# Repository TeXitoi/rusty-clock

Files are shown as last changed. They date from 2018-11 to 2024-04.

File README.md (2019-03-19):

# Rusty clock 

An alarm clock in pure bare metal embedded rust (no OS). It features pressure, temperature, humidity, monophonic alarm on a e-paper display. The 5 programmable alarms can ring one time (and never repeat) or every week day that you want (for example only Monday and Thursday).

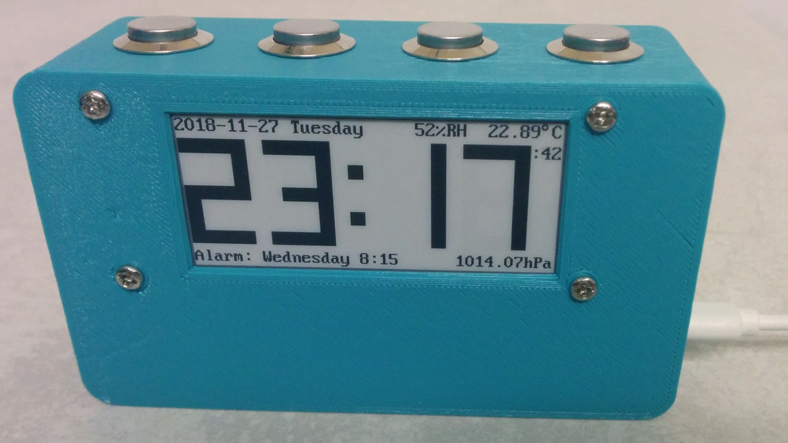
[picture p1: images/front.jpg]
front


You can also look at the [gallery](gallery.md).

## Hardware

The hardware used in this project is
- a [blue pill board](https://wiki.stm32duino.com/index.php?title=Blue_Pill) featuring a STM32F103C8 microcontroller (20KiB RAM, 64 KiB flash, ARM Cortex M3 @72MHz);
- a [2.9" WaveShare e-paper display](https://www.waveshare.com/wiki/2.9inch_e-Paper_Module) (296x128 black or white pixels);
- a [BME280 sensor](https://www.bosch-sensortec.com/bst/products/all_products/bme280) for temperature, humidity and pressure on a [I2C compatible PCB (VIN, GND, SCL and SDA pins)](https://www.aliexpress.com/item/a/32847825408.html);
- a [2" speaker](https://www.aliexpress.com/item/a/32728713916.html) driven by PWM;
- 4 [16mm normally open push buttons](https://www.aliexpress.com/item/a/32867071630.html) (cancel, previous, next, OK);
- a [3D printed case](cad/);
- USB power plug;
- micro USB cable;
- a CR20xx coin battery (optional);
- wires (I use [single core wires](https://www.aliexpress.com/item/a/32832816460.html)) and soldering set;
- 4 2mm wood screws.

You also need a [ST-Link v2](https://www.aliexpress.com/item/a/32719963657.html) to flash and debug.

Everything can be purchased on [Aliexpress](https://my.aliexpress.com/wishlist/shared.htm?groupId=100000007706754). Budget is around US $40 without the 3D printed case and soldering set.

## Wiring

Everything is plugged directly to the blue pill board.

E-paper display to blue pill board:
- BUSY -> A10
- RST -> A9
- DC -> A8
- CS -> B12
- CLK -> B13
- DIN -> B15
- GND -> G
- VCC -> 3.3

BME280 to blue pill board:
- VIN -> 3.3
- GND -> G
- SCL -> B6
- SDA -> B7

Buttons are connected to the blue pill board between G and
- A6 for cancel
- A7 for previous
- B0 for next
- B1 for OK

The speaker is connected to the blue pill board between A0 and A1.

Coin battery to blue pill board:
- (-) -> G
- (+) -> VB

Plug the micro USB connector of the blue pill board to a USB power supply (or a computer).

## Compiling and flashing

For compiling and flashing, please refer to [the blue pill quickstart](https://github.com/TeXitoi/blue-pill-quickstart/blob/master/README.md).

Basically:

```shell
curl https://sh.rustup.rs -sSf | sh
rustup target add thumbv7m-none-eabi
sudo apt-get install gdb-arm-none-eabi openocd
cd rusty-clock
# connect ST-Link v2 to the blue pill and the computer
# openocd in another terminal
cargo run --release
```

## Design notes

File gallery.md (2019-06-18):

# Gallery

## Breadboard prototype

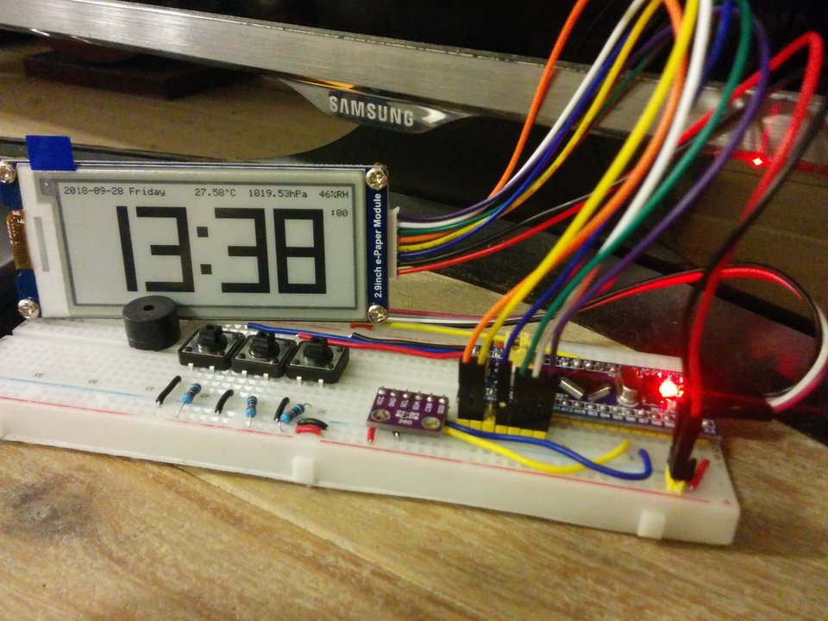
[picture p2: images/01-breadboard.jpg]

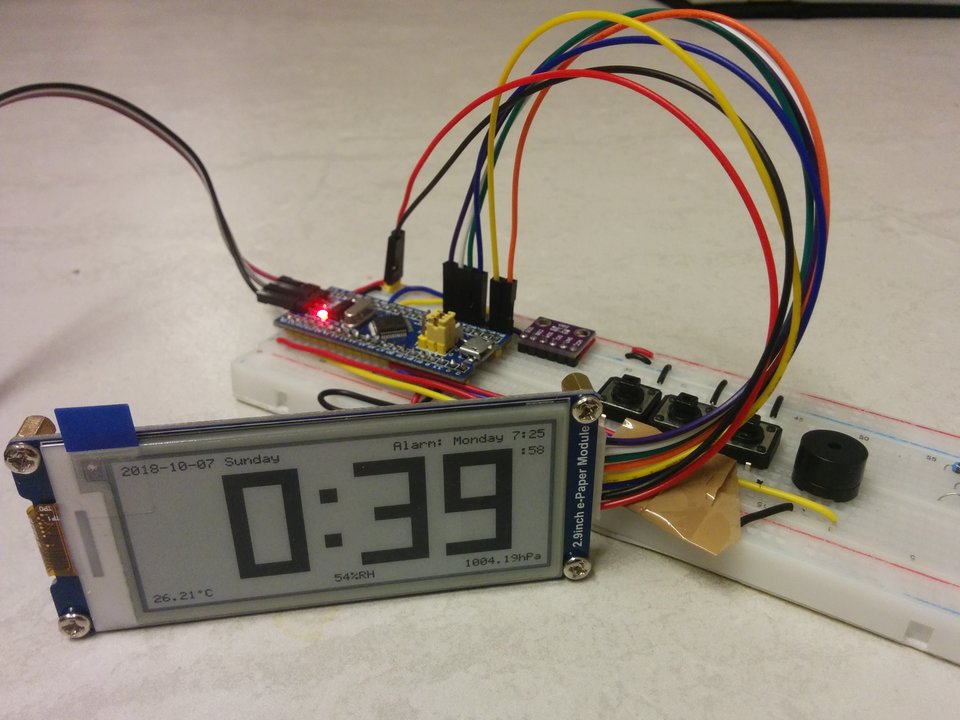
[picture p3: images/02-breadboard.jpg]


## Beta box

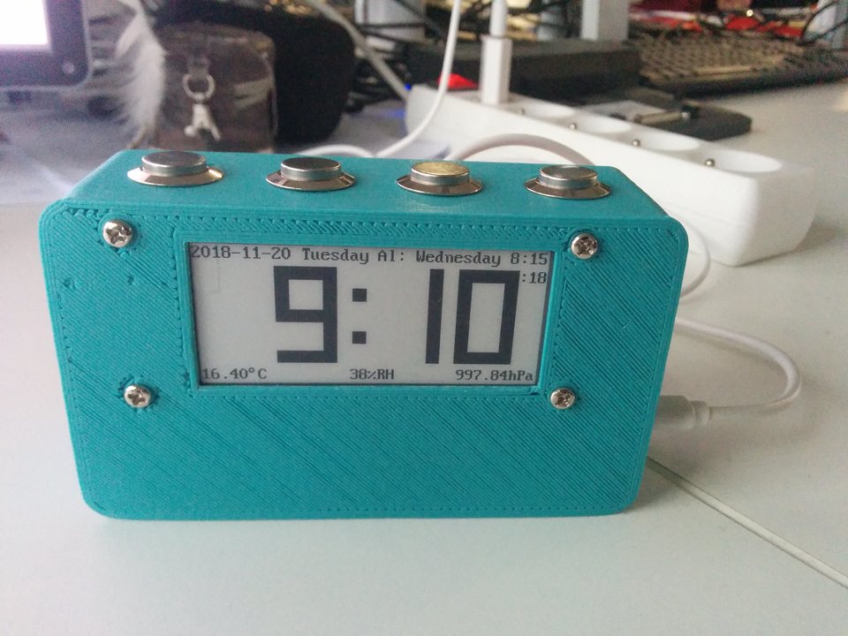
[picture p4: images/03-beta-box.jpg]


## The first functionnal alarm clock


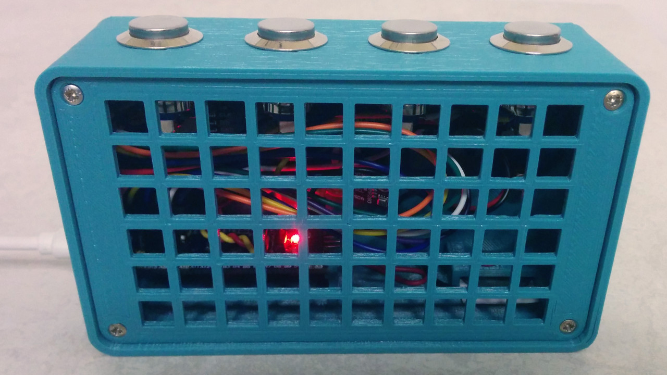
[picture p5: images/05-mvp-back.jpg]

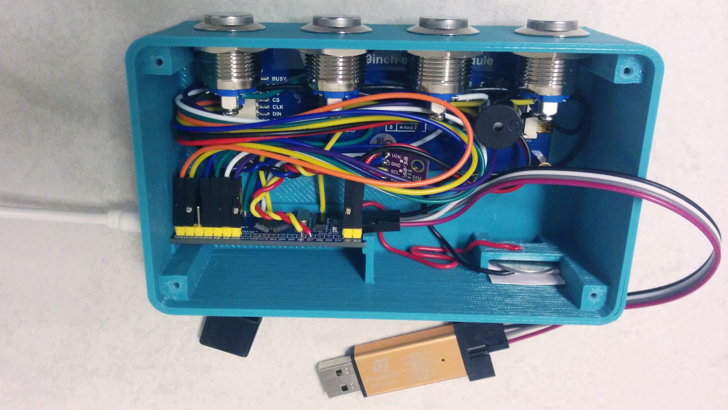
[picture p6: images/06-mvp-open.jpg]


## 3D rendering of the box v2

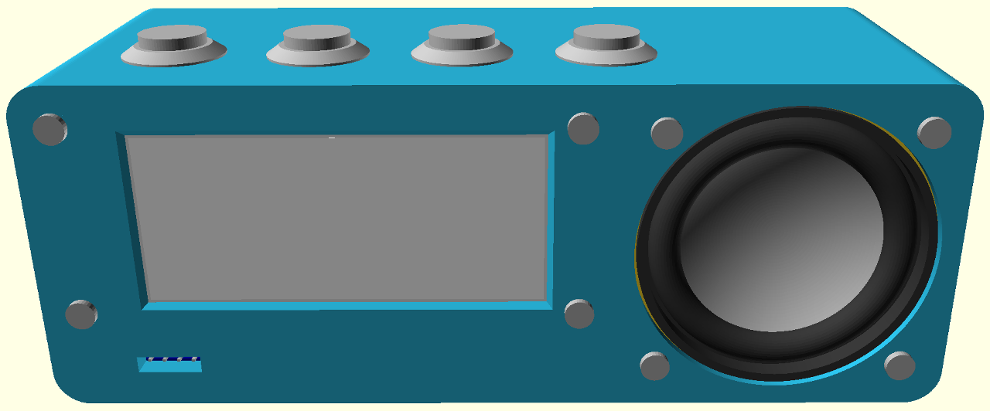
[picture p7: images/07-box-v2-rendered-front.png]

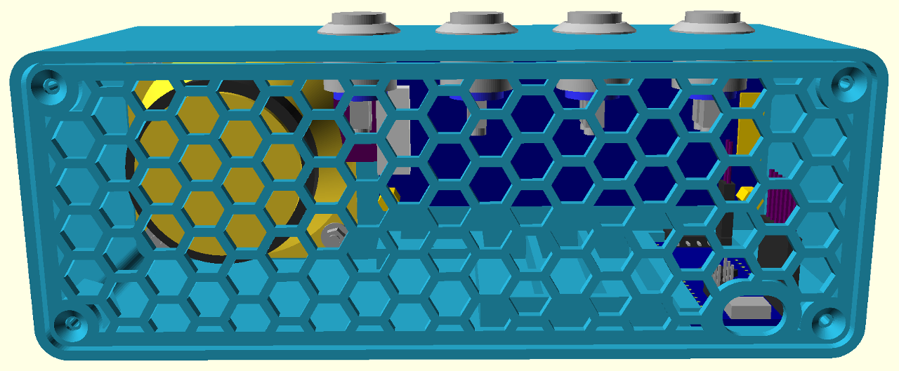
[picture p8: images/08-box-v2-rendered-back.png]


## The alarm clock v2

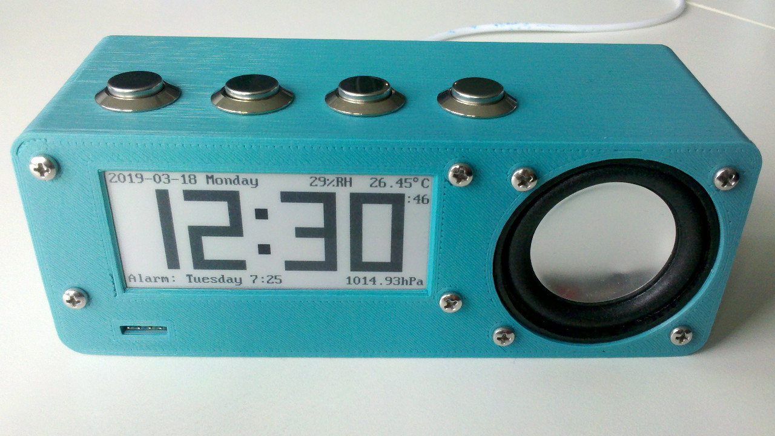
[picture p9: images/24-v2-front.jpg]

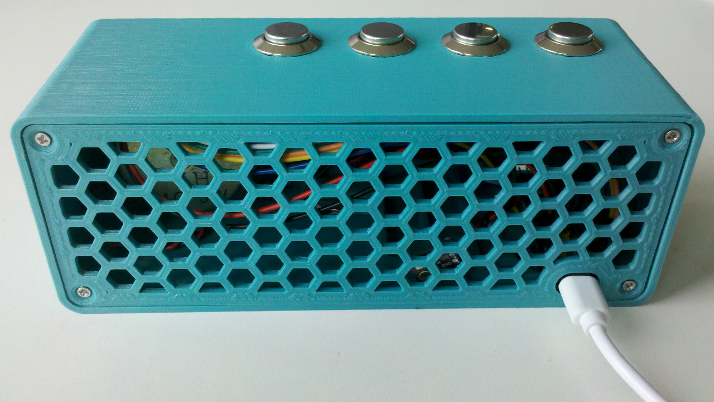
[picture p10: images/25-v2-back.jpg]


## @caemor tests

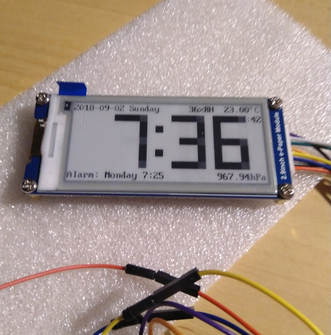
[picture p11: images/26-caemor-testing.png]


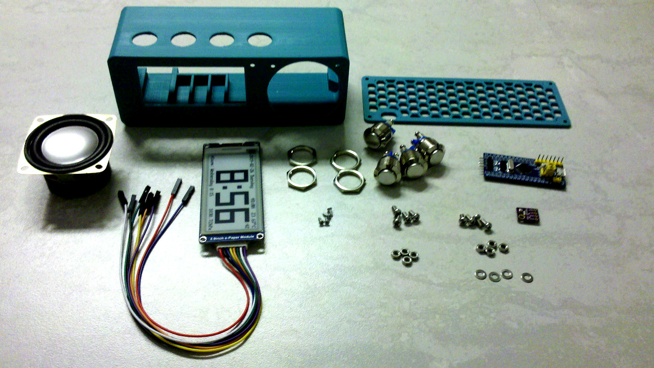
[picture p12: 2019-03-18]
images/09-hardware.jpg

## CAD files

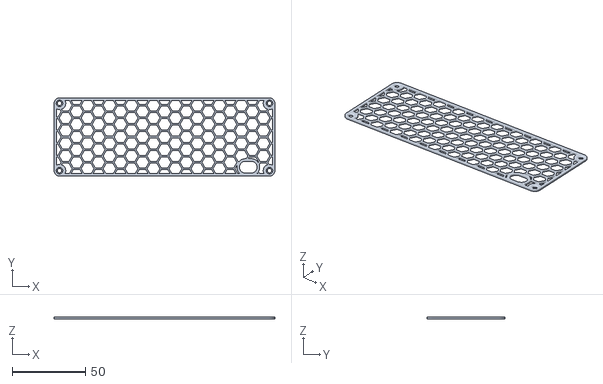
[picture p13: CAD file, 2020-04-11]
cad/box-v2/back.stl
150.9 x 53.5 x 1.20

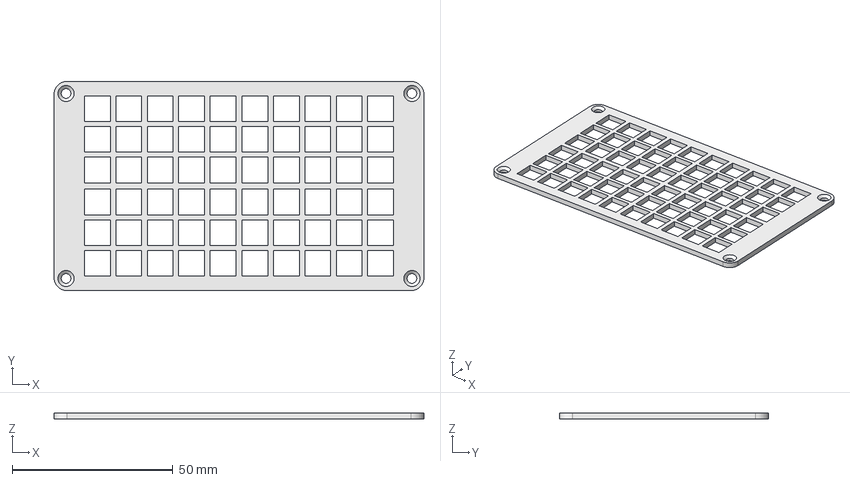
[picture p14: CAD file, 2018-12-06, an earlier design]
cad/box-v1/back-panel.fcstd
115.0 x 65.0 x 2.00 mm

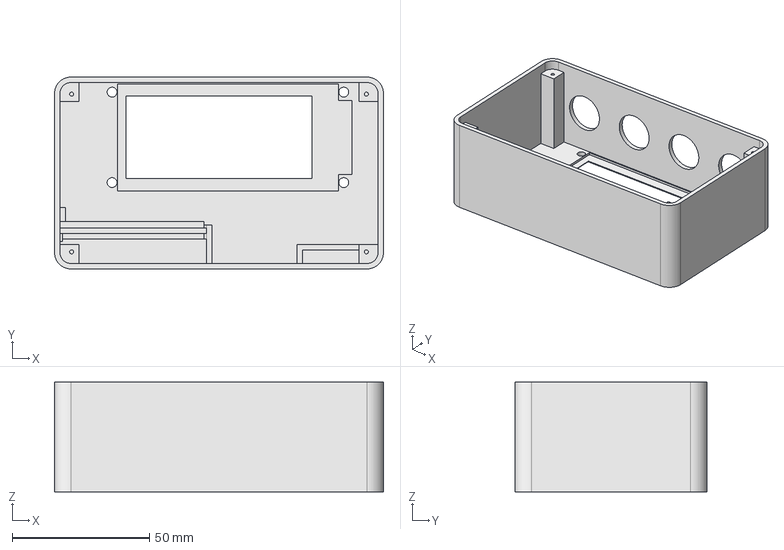
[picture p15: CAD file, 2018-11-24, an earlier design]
cad/box-v1/box.fcstd
120.0 x 70.0 x 40.0 mm

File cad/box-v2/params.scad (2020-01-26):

thickness=0.6*3;

box_color=[40/255, 177/255, 214/255];

// bluepill including tolerance
bluepill_width=53.5;
bluepill_height=23;

backpanel_pilone_size=7;
backpanel_insertion_size=1;
box_width=155;
box_height=54+2*(thickness);
box_depth=bluepill_width + 2 + 2*thickness + backpanel_insertion_size;
box_rounding=6;
box_pilone_height=box_depth-thickness-backpanel_insertion_size;

bluepill_x=box_width/2-thickness-backpanel_pilone_size - 23/2;
bluepill_y=-box_height/2+backpanel_pilone_size - 0.5 * thickness;

backpanel_hole_coords=[
  for (i=[-1,1])
    for (j=[-1,1])
      [i * (box_width/2-thickness-backpanel_pilone_size+3),
       j * (box_height/2-thickness-backpanel_pilone_size+3)]
];

legend_depth=0.6;
legend_size=6;
legend_texts=["C", "<", ">", "OK"];
legend_font="Latin Modern Sans Quotation:style=8 Bold";
button_legend_offset=15;
button_spacing=25;
button_x=box_width/2-9-2*button_spacing;
button_coords=[ for (i=[1.5:-1:-1.5]) [i*button_spacing+button_x, box_height/2, box_depth/2] ];
module button_placement() {
  for (coord = button_coords)
    translate(coord)
      rotate([-90, 0, 0])
      children();
}

module epaper_placement() {
  x_placement=box_width/2-thickness-90.5/2-5.5/2-2;
  y_placement=box_height/2-thickness-39/2-2;
  translate([x_placement, y_placement, thickness-1]) rotate([0,180,0]) children();
}

module speaker_placement() {
  translate([-box_width/2+54/2+thickness, 0, thickness]) rotate([0,180,0]) children();
}

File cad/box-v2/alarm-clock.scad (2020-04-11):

use <box.scad>
use <back.scad>
use <button.scad>
use <epaper.scad>
use <speaker.scad>
use <blue-pill.scad>
include <params.scad>
//include <printing.scad>

box();

epaper_placement() epaper();

speaker_placement() speaker();

button_placement() button(thickness);

translate([bluepill_x, bluepill_y, thickness + 53/2 + 2])
rotate([-90, 90, 0])
blue_pill();

translate([0,0,box_pilone_height]) back();

// coin baterry
//translate([bluepill_x-23.5,-box_height/2+2,10+2]) rotate([-90,0,0]) color([0.7, 0.7, 0.7]) cylinder(d=20, h=3.2);

/*
translate([0, box_height/2, box_depth - 28/2])
rotate([90,0,0])
color([0.1,0.1,0.1])
cube([100,28,2], center=true);
*/

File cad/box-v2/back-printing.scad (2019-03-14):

use <back.scad>
include <printing.scad>

back();

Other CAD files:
cad/box-v2/back.scad
cad/box-v1/back-panel.stl
cad/box-v1/box.stl
cad/box-v2/battery.scad
cad/box-v2/blue-pill.scad
cad/box-v2/box-printing.scad
cad/box-v2/box.scad
cad/box-v2/button.scad
cad/box-v2/epaper.scad
cad/box-v2/printing.scad
cad/box-v2/screws.scad
cad/box-v2/speaker.scad
cad/box-v2/utils.scad

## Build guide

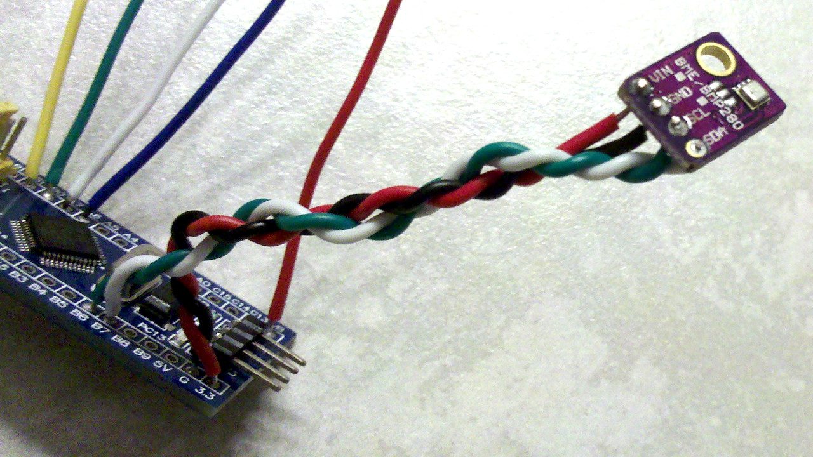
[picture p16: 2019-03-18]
images/23-bme280-soldered.jpg

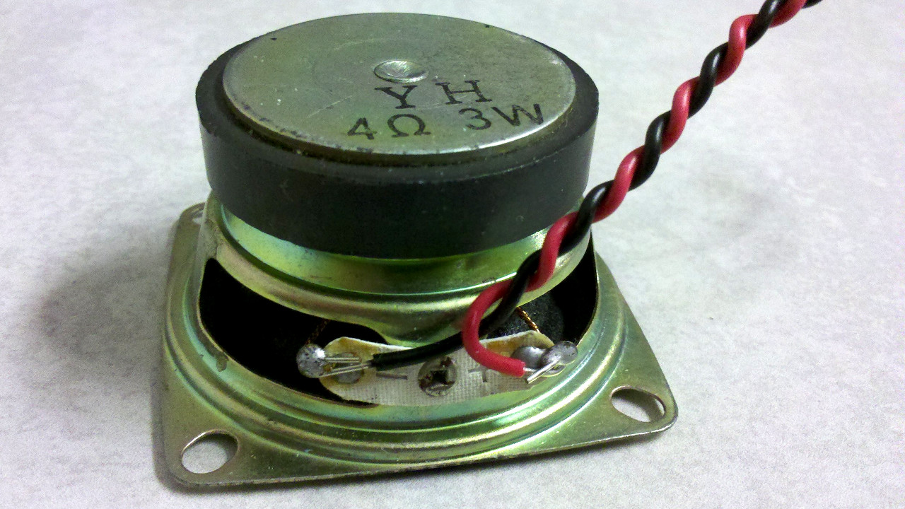
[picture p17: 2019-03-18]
images/12-speaker-soldering.jpg

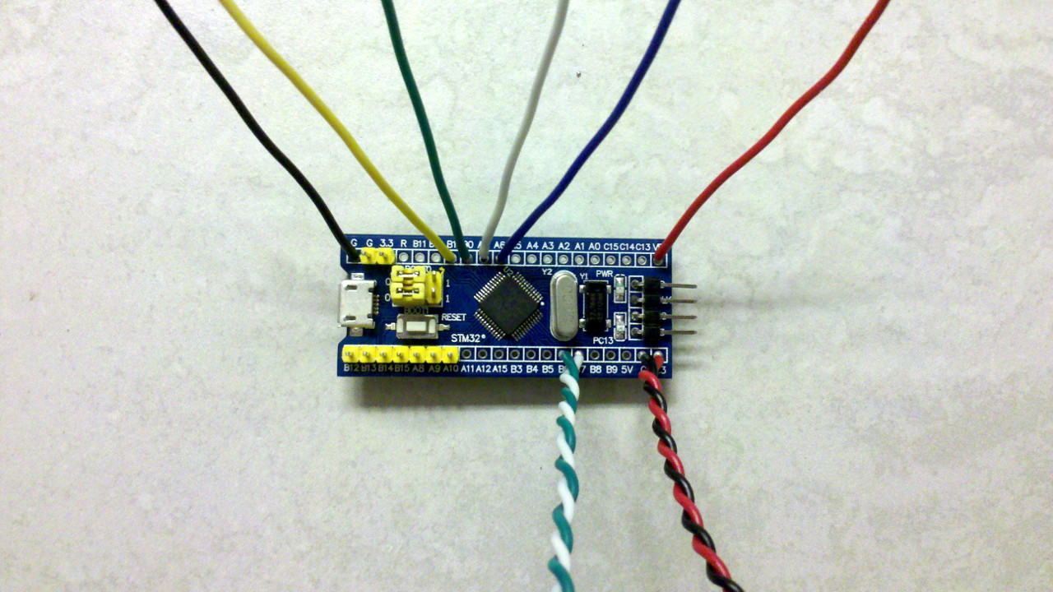
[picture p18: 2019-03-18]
images/21-wires-soldered.jpg

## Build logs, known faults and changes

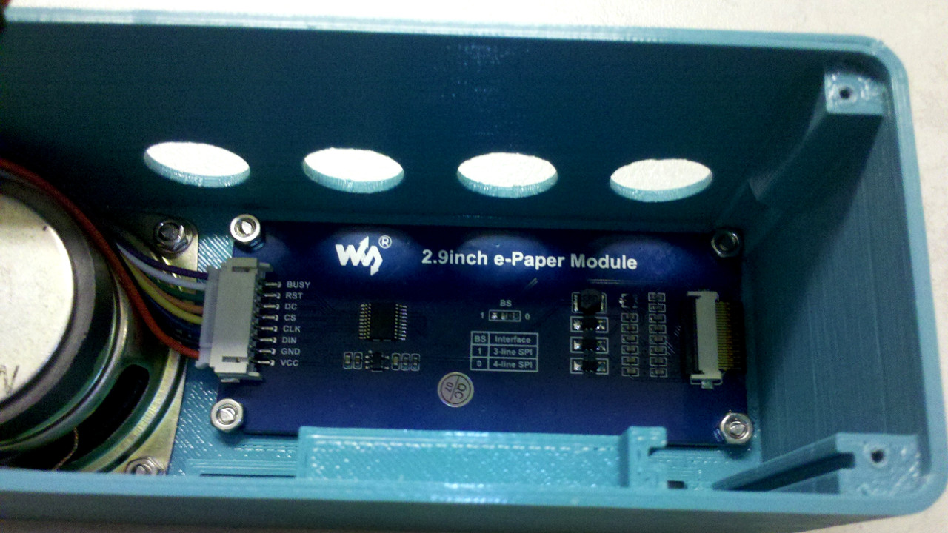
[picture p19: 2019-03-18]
images/17-fix-display-back.jpg

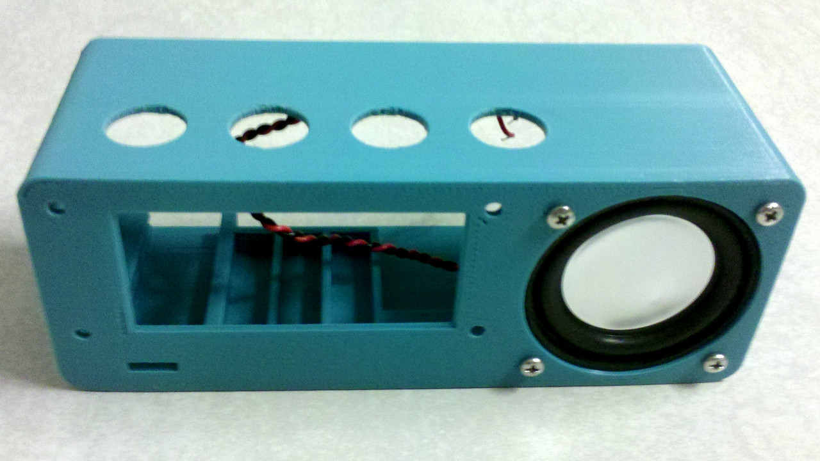
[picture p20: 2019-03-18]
images/14-fix-speaker-front.jpg

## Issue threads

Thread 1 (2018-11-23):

Support schematic circuit diagram

ZhangHanDong, 2018-11-23:
```
blackang3r: Good. Is there a schematic circuit diagram?

TeXitoi : Not yet. You can find the used pin in the source code.
That's planned. You can open an issue to know when it's done, and it will motivate me to do it fast ;-)
```

Look forward to your schematic circuit diagram.  😆

TeXitoi, 2018-11-23:
I've added a wireing description in the README. That's not a schematic circuit diagram, but it should do the job.

ZhangHanDong, 2018-11-23:
@TeXitoi I  see， Thank you

Closed 2018-11-23.

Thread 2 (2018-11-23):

Case improvements

TeXitoi, 2018-11-23:
- [x] button holes must be 16mm not 17
- [x] enlarge the SWD pocket
- [x] chamfer around the display pocket
- [x] lower the board
- [x] enlarge a bit the display screw holes
- [x] add a back
- [x] add coin battery holder
- [x] shorten the back screw hole to have the back a bit inside

Closed 2018-11-26.

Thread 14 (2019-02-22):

Questions while trying to use epd-waveshare instead of il3820

caemor, 2019-02-22:
I tried to use my epd_waveshare crate for this app instead of the il3820 which is basically just a slightly different driver for the same display. (the epd-crate also includes 2 other epds).

The biggest problem I have right now is that ui:view always creates a new buffer/display_ribbon_left. Is there a reason for this? (https://github.com/TeXitoi/rusty-clock/blob/master/portable/src/ui/mod.rs#L152)

TeXitoi, 2019-02-22:
To mimich the ELM architecture.

Also to allocate only when needed, and to not depend on stm32 types without generics everywhere.

I quite like that the buffer is completely decoupled from the driver. I begun the il3820 crate before you publish your, and I never take the time to polish it for publication.

Now, the size of the display is quite hard coded in the rendering, some work need to be done if we want to use different screen size.

TeXitoi, 2019-02-23:
Do you plan to construct a clock? I'd be interested by photos, even just on a breadboard!

caemor, 2019-02-23:
Yes, I am trying to use your clock here :-D
But I am still waiting for a few parts to arrive :-)

TeXitoi, 2019-03-12:
I see you've done a lot of refactor to your driver. One time you publish 0.3 on crates.io, I'll happily accept a PR using your library that looks much better than mine.

Any news on the photos of your project?

caemor, 2019-03-12:
I'm hanging on a bug where it doesn't set the fast refresh rate once more after the slow full refresh at the full hour. As soon as it's completly working I am happy to publish ;-)

caemor, 2019-04-04:
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

a little screenshot of running your clock (although without the case and without buttons atm)

TeXitoi, 2019-06-18:
If you have any more photos, I'll happily add them to the gallery.

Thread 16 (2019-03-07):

Make a new box

TeXitoi, 2019-03-07:
Make a new [box](https://github.com/TeXitoi/rusty-clock/tree/master/cad/box-v2) with:
 - [x] speaker
 - [x] accessible debugger without removing the backpanel
 - [x] AAA battery holder (just in case)

TODO:
 - [x] box
 - [x] back panel
 - [x] printing everything

Closed 2019-03-18.

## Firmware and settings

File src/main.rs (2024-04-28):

#![no_main]
#![no_std]

#[cfg(not(test))]
extern crate panic_semihosting;

use embedded_hal::digital::v1_compat::{OldInputPin, OldOutputPin};
use epd_waveshare::prelude::*;
use portable::datetime::DateTime;
use portable::{alarm, button, datetime, ui};
use pwm_speaker::songs::SO_WHAT;
use rtic::app;
use stm32f1xx_hal::prelude::*;
use stm32f1xx_hal::{delay, gpio, i2c, rtc, spi, stm32, timer};

mod sound;

type I2C = i2c::BlockingI2c<
    stm32::I2C1,
    (
        gpio::gpiob::PB6<gpio::Alternate<gpio::OpenDrain>>,
        gpio::gpiob::PB7<gpio::Alternate<gpio::OpenDrain>>,
    ),
>;
type Button0Pin = gpio::gpioa::PA6<gpio::Input<gpio::PullUp>>;
type Button1Pin = gpio::gpioa::PA7<gpio::Input<gpio::PullUp>>;
type Button2Pin = gpio::gpiob::PB0<gpio::Input<gpio::PullUp>>;
type Button3Pin = gpio::gpiob::PB1<gpio::Input<gpio::PullUp>>;
type Spi = spi::Spi<
    stm32::SPI2,
    stm32f1xx_hal::spi::Spi2NoRemap,
    (
        gpio::gpiob::PB13<gpio::Alternate<gpio::PushPull>>,
        gpio::gpiob::PB14<gpio::Input<gpio::Floating>>,
        gpio::gpiob::PB15<gpio::Alternate<gpio::PushPull>>,
    ),
>;
type EPaperDisplay = epd_waveshare::epd2in9::EPD2in9<
    Spi,
    OldOutputPin<gpio::gpiob::PB12<gpio::Output<gpio::PushPull>>>, // cs/nss
    OldInputPin<gpio::gpioa::PA10<gpio::Input<gpio::Floating>>>,   // busy
    OldOutputPin<gpio::gpioa::PA8<gpio::Output<gpio::PushPull>>>,  // dc
    OldOutputPin<gpio::gpioa::PA9<gpio::Output<gpio::PushPull>>>,  // rst
>;

#[app(device = stm32f1xx_hal::stm32, peripherals = true)]
const APP: () = {
    struct Resources {
        rtc_dev: rtc::Rtc,
        bme280: bme280::BME280<I2C, delay::Delay>,
        alarm_manager: alarm::AlarmManager,
        sound: sound::Sound,
        button0: button::Button<Button0Pin>,
        button1: button::Button<Button1Pin>,
        button2: button::Button<Button2Pin>,
        button3: button::Button<Button3Pin>,
        display: EPaperDisplay,
        spi: Spi,
        ui: ui::Model,
        #[init(true)]
        full_update: bool,
        timer: timer::CountDownTimer<stm32::TIM3>,
        backup_domain: stm32f1xx_hal::backup_domain::BackupDomain,
    }

    #[init(spawn = [msg])]
    fn init(mut c: init::Context) -> init::LateResources {
        let mut flash = c.device.FLASH.constrain();
        let mut rcc = c.device.RCC.constrain();
        let mut afio = c.device.AFIO.constrain(&mut rcc.apb2);
        let clocks = rcc
            .cfgr
            .use_hse(8.mhz())
            .sysclk(72.mhz())
            .pclk1(36.mhz())
            .freeze(&mut flash.acr);
        let mut gpioa = c.device.GPIOA.split(&mut rcc.apb2);
        let mut gpiob = c.device.GPIOB.split(&mut rcc.apb2);

        let c1 = gpioa.pa0.into_alternate_push_pull(&mut gpioa.crl);
        let c2 = gpioa.pa1.into_alternate_push_pull(&mut gpioa.crl);
        let c3 = gpioa.pa2.into_alternate_push_pull(&mut gpioa.crl);
        let c4 = gpioa.pa3.into_alternate_push_pull(&mut gpioa.crl);
        let mut pwm = timer::Timer::tim2(c.device.TIM2, &clocks, &mut rcc.apb1)
            .pwm::<timer::Tim2NoRemap, _, _, _>((c1, c2, c3, c4), &mut afio.mapr, 440.hz());
        pwm.0.enable();
        pwm.1.enable();
        let speaker = pwm_speaker::Speaker::new(pwm.0, clocks);

        let button0_pin = gpioa.pa6.into_pull_up_input(&mut gpioa.crl);
        let button1_pin = gpioa.pa7.into_pull_up_input(&mut gpioa.crl);
        let button2_pin = gpiob.pb0.into_pull_up_input(&mut gpiob.crl);
        let button3_pin = gpiob.pb1.into_pull_up_input(&mut gpiob.crl);

        let mut timer =
            timer::Timer::tim3(c.device.TIM3, &clocks, &mut rcc.apb1).start_count_down(1.khz());
        timer.listen(timer::Event::Update);

        let mut backup_domain = rcc
            .bkp
            .constrain(c.device.BKP, &mut rcc.apb1, &mut c.device.PWR);
        let mut rtc_dev = rtc::Rtc::rtc(c.device.RTC, &mut backup_domain);
        if rtc_dev.current_time() < 100 {
            let today = DateTime {
                year: 2020,
                month: 1,
                day: 1,
                hour: 0,
                min: 0,
                sec: 0,
                day_of_week: datetime::DayOfWeek::Wednesday,
            };
            if let Some(epoch) = today.to_epoch() {
                rtc_dev.set_time(epoch);
            }
        }
        rtc_dev.listen_seconds();

        let mut alarm_manager = alarm::AlarmManager::default();
        for i in 0..5 {
            let d0 = backup_domain.read_data_register_low(i * 2);
            let d1 = backup_domain.read_data_register_low(i * 2 + 1);
            if let Some(alarm) = alarm::Alarm::try_from(d0 as u32 | (d1 as u32) << 16) {
                alarm_manager.alarms[i] = alarm;
            }
        }

        let mut delay = delay::Delay::new(c.core.SYST, clocks);

        let sck = gpiob.pb13.into_alternate_push_pull(&mut gpiob.crh);
        let miso = gpiob.pb14;
        let mosi = gpiob.pb15.into_alternate_push_pull(&mut gpiob.crh);
        let mut spi = spi::Spi::spi2(
            c.device.SPI2,
            (sck, miso, mosi),
            epd_waveshare::SPI_MODE,
            4.mhz(),
            clocks,
            &mut rcc.apb1,
        );
        let mut il3820 = epd_waveshare::epd2in9::EPD2in9::new(
            &mut spi,
            gpiob.pb12.into_push_pull_output(&mut gpiob.crh).into(),
            gpioa.pa10.into_floating_input(&mut gpioa.crh).into(),
            gpioa.pa8.into_push_pull_output(&mut gpioa.crh).into(),
            gpioa.pa9.into_push_pull_output(&mut gpioa.crh).into(),
            &mut delay,
        )
        .unwrap();
        il3820.set_lut(&mut spi, Some(RefreshLUT::QUICK)).unwrap();
        il3820.clear_frame(&mut spi).unwrap();

        c.core.DCB.enable_trace();
        c.core.DWT.enable_cycle_counter();
        let pb6 = gpiob.pb6.into_alternate_open_drain(&mut gpiob.crl);
        let pb7 = gpiob.pb7.into_alternate_open_drain(&mut gpiob.crl);
        let i2c = i2c::I2c::i2c1(
            c.device.I2C1,
            (pb6, pb7),
            &mut afio.mapr,
            i2c::Mode::Fast {
                frequency: 400.khz().into(),
                duty_cycle: i2c::DutyCycle::Ratio2to1,
            },
            clocks,
            &mut rcc.apb1,
        );
        let i2c = i2c::blocking_i2c(i2c, clocks, 200, 10, 200, 200);
        let mut bme280 = bme280::BME280::new_primary(i2c, delay);
        bme280.init().expect("i2c init error");

        c.spawn
            .msg(ui::Msg::AlarmManager(alarm_manager.clone()))
            .unwrap();

        init::LateResources {
            rtc_dev,
            bme280,
            sound: sound::Sound::new(speaker),
            button0: button::Button::new(button0_pin),
            button1: button::Button::new(button1_pin),
            button2: button::Button::new(button2_pin),
            button3: button::Button::new(button3_pin),
            display: il3820,
            spi,
            ui: ui::Model::init(),
            alarm_manager,
            timer,
            backup_domain,
        }
    }

    #[task(binds = TIM3, priority = 4, spawn = [msg], resources = [button0, button1, button2, button3, sound, timer])]
    fn tick(c: tick::Context) {
        c.resources.timer.clear_update_interrupt_flag();

        if let button::Event::Pressed = c.resources.button0.poll() {
            c.resources.sound.stop();
            c.spawn.msg(ui::Msg::ButtonCancel).unwrap();
        }
        if let button::Event::Pressed = c.resources.button1.poll() {
            c.spawn.msg(ui::Msg::ButtonMinus).unwrap();
        }
        if let button::Event::Pressed = c.resources.button2.poll() {
            c.spawn.msg(ui::Msg::ButtonPlus).unwrap();
        }
        if let button::Event::Pressed = c.resources.button3.poll() {
            c.spawn.msg(ui::Msg::ButtonOk).unwrap();
        }
        c.resources.sound.poll();
    }

    #[task(binds = RTC, priority = 3, spawn = [msg], resources = [rtc_dev, bme280, alarm_manager, sound])]
    fn rtc_task(mut c: rtc_task::Context) {
        c.resources.rtc_dev.clear_second_flag();

        let datetime = DateTime::new(c.resources.rtc_dev.current_time());
        if datetime.sec == 0 && c.resources.alarm_manager.must_ring(&datetime) {
            c.resources
                .sound
                .lock(|alarm| alarm.play(&SO_WHAT, 10 * 60));
            let manager = c.resources.alarm_manager.clone();
            c.spawn.msg(ui::Msg::AlarmManager(manager)).unwrap();
        }
        c.spawn.msg(ui::Msg::DateTime(datetime)).unwrap();

        let msg = if let Ok(measurements) = c.resources.bme280.measure() {
            ui::Msg::Environment(crate::ui::Environment {
                pressure: measurements.pressure as u32,
                temperature: (measurements.temperature * 100.) as i16,
                humidity: measurements.humidity as u8,
            })
        } else {
            ui::Msg::FailEnvironment
        };
        c.spawn.msg(msg).unwrap();
    }

    #[task(priority = 2, capacity = 16, spawn = [msg], resources = [ui, rtc_dev, full_update, alarm_manager, backup_domain])]
    fn msg(mut c: msg::Context, msg: ui::Msg) {
        use crate::ui::Cmd::*;
        for cmd in c.resources.ui.update(msg) {
            match cmd {
                UpdateRtc(dt) => {
                    if let Some(epoch) = dt.to_epoch() {
                        c.resources.rtc_dev.lock(|rtc| {
                            let _ = rtc.set_time(epoch);
                        });
                        c.spawn.msg(ui::Msg::DateTime(dt)).unwrap();
                    }
                }
                UpdateAlarm(alarm, i) => {
                    let data = alarm.as_u32();
                    c.resources
                        .backup_domain
                        .write_data_register_low(i * 2, data as u16);
                    c.resources
                        .backup_domain
                        .write_data_register_low(i * 2 + 1, (data >> 16) as u16);
                    let manager = c.resources.alarm_manager.lock(|m| {
                        m.alarms[i] = alarm;
                        m.clone()
                    });
                    c.spawn.msg(ui::Msg::AlarmManager(manager)).unwrap();
                }
                FullUpdate => *c.resources.full_update = true,
            }
        }
        rtic::pend(stm32::Interrupt::EXTI1);
    }

    #[task(binds = EXTI1, priority = 1, resources = [ui, display, spi, full_update])]
    fn render(mut c: render::Context) {
        let model = c.resources.ui.lock(|model| model.clone());
        let display = model.view();
        let full_update = c
            .resources
            .full_update
            .lock(|fu| core::mem::replace(&mut *fu, false));
        if full_update {
            c.resources
                .display
                .set_lut(&mut *c.resources.spi, Some(RefreshLUT::FULL))
                .unwrap();
        }

        c.resources
            .display
            .update_frame(&mut *c.resources.spi, &display.buffer())
            .unwrap();
        c.resources
            .display
            .display_frame(&mut *c.resources.spi)
            .unwrap();

        if full_update {
            // partial/quick refresh needs only be set when a full update was run before
            c.resources
                .display
                .set_lut(&mut *c.resources.spi, Some(RefreshLUT::QUICK))
                .unwrap();
        }
    }

    // Interrupt handlers used to dispatch software tasks
    extern "C" {
        fn EXTI2();
    }
};

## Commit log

2018-08-16 add bme280: compile and run, but garbadge from sensors
2018-08-25 stop alarm with button
2018-08-28 Switch to rust-lld
2018-09-04 switch to an Elm Architecture
2018-09-04 using buttons
2018-09-07 add minus button
2018-09-26 remove led as that break RTC
2018-10-02 no more unstable features
    [main.rs]
2018-10-03 update to stm32f103xx-hal personal fork
2018-10-14 add cad of the box
    [box.fcstd, box.stl]
2018-10-15 fix usb hole
    [box.fcstd, box.stl]
2018-10-15 add swo pocket
    [box.fcstd, box.stl]
2018-10-19 screen pocket + corner rounding
    [box.fcstd, box.stl]
2018-10-20 Fix AlarmManager::next_ring with unit test
    [main.rs]
2018-10-20 move ui and button in portable
2018-10-23 add a pocket for the wire of the screen
    [box.fcstd, box.stl]
2018-11-21 Cancel button + tweek headers
2018-11-23 Wireing description
    fix #1
2018-11-23 fix typo + add coin battery reference
2018-11-23 case improvements
    [box.fcstd]
2018-11-23 lower the bluepill altitude
    [box.fcstd]
2018-11-23 higher USB
    [box.fcstd]
2018-11-23 holes for small backpanel screws
    [box.fcstd]
2018-11-24 redo the pocket for screen
    [box.fcstd, box.stl]
2018-11-24 coin battery holder
    [box.fcstd, box.stl]
2018-11-26 add a back panel
    [back-panel.fcstd, back-panel.stl]
2018-12-06 fix back panel
    [back-panel.fcstd, back-panel.stl]
2018-12-06 I2C: change duty ratio
2018-12-06 remove unwrap on I2C
2018-12-12 update to stm32f103xx 0.11
2018-12-14 fix printing negative values (esp. temperature)
2018-12-14 improve the cancel button behavior
    fix #4
2018-12-19 switch to RTFM task for msg
2019-01-05 move freecad files in a directory
    [back-panel.fcstd, back-panel.stl, box.fcstd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]
2019-01-05 button and blue pill in scad
    [blue-pill.scad, button.scad]
2019-01-05 cleanup code
    [blue-pill.scad]
2019-01-10 epaper model
    [epaper.scad]
2019-01-12 box with buttons
    [alarm-clock.scad, box.scad, epaper.scad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]
2019-01-12 epaper pocket
    [alarm-clock.scad, box.scad, button.scad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]
2019-01-13 pilone holes
    [box.scad, params.scad]
2019-01-13 add box.stl
    [alarm-clock.scad, box-printing.scad, box.stl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]
2019-01-13 bluepill support
    [alarm-clock.scad, blue-pill.scad, box.scad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]
2019-01-20 speaker pocket
    [speaker.scad]
2019-01-20 screws on speaker
    [epaper.scad, screws.scad, speaker.scad]
2019-01-20 add speaker to box
    [alarm-clock.scad, box.scad, params.scad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]
2019-01-26 module for buttons
    [alarm-clock.scad, box.scad, params.scad]
2019-01-26 bluepill on the other side + duponds
    [alarm-clock.scad, blue-pill.scad, box.scad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]
2019-01-26 horizontal placement
    [params.scad]
2019-01-27 45° on pocket corners
    [epaper.scad, params.scad, speaker.scad]
2019-01-28 battery holders
    [battery.scad, box.scad, box.stl]
2019-02-12 add solar panel
    [alarm-clock.scad]
2019-02-15 count measurement failures instead of returning empty measurements
    [main.rs]
2019-02-26 some tweeks after first print
    [alarm-clock.scad, battery.scad, box.scad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]
2019-03-14 add back pannel
    [alarm-clock.scad, back-printing.scad, back.scad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]
2019-03-14 backpanel improvement
    [back.scad, back.stl]
2019-03-15 Add prototype images
2019-03-16 enable pwm on A1 for compatibility with future softsynth
2019-06-17 Switch to epd_waveshare crate instead of il3820 (#18)
2019-06-17 using RTC from stm32f1xx-hal
2020-01-25 legend on the buttons and thickness tunning
    [back.scad, back.stl, blue-pill.scad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]
2020-01-26 move a bit the backpanel holes
    [back.stl, box.stl, params.scad]
2020-04-11 fix back
    [back.scad, back.stl]
2020-04-11 fix coin battery pocket
    [alarm-clock.scad, box.scad, box.stl]
2020-04-13 better epaper pocket
    [box.stl, epaper.scad]
2021-04-25 Fix typo in Portable::button Reseased->Released
